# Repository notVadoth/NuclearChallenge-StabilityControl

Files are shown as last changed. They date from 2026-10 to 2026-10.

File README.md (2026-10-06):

# Nuclear Innovation Challenge: Reactor Stability Control (Dye Analogue)

A bench-scale analogue of reactor control for the 2026 Nuclear Innovation Challenge (Controls and Instrumentation track). Green food dye stands in for boron: adding dye "lowers the control rods", diluting with clear water "raises" them. A colour sensor reads the dye concentration, and pumps hold it at a target. The long-term goal is a holistic system that predicts unstable conditions and recommends actions before they happen.

Built on the challenge's base code: [IdeasClinicUWaterloo/F26-NuclearIC](https://github.com/IdeasClinicUWaterloo/F26-NuclearIC)

Canva view link: https://canva.link/ud9t2yi2hbv6vku

## Contents

| Folder | What it is |
| --- | --- |
| `Pump Control App/Pump Control.html` | Desktop control app. Open in Chrome or Edge, no install. Connects to the Arduino over USB (Web Serial). |
| `Pump Control App/pump_control_serial/` | Arduino sketch the app talks to: pumps, colour sensor, stored calibration, safety limits. |
| `Beaker Level Camera/Beaker Level Camera.html` | Standalone page that measures the tank level in mL from a phone used as a webcam. No Arduino needed. |
| `BeerLambertCalibrator/` | The repo's calibration sketch, extended to print live concentration and hold a saved calibration. Used from the Serial Monitor. |
| `dye_concentration_controller/` | The repo's controller sketch with a 10-second-per-pump test mode added, plus a local copy of the PID library (Brett Beauregard, MIT licence) so it compiles without installing it. |
| `Docs/Nuclear Innovation Challenge.pptx` | Group 9's presentation: challenge problem, background, the control rod simulator, experiment and observations, setbacks, safety and regulations, citations and AI disclosure. |
| `Docs/calibration-2026-10-03.svg` | Graph of the 3 Oct 2026 calibration: absorbance of the five standards against concentration, with the fitted line. |
| `Media/` | Photos of the rig, the bench setup, the control app in use and the team. |
| `Schematic/` | KiCad project of the rig's wiring (`dye-rig.kicad_sch`) and an SVG export of it (`dye-rig.svg`). |

## Hardware

Arduino UNO R4 Minima, SEN0101 (TCS3200) colour sensor, three 3 V pumps (dye, clear, waste) on two DRV8833 drivers powered by a 9 V battery, 500 mL control tank run at 350 mL (limit 450 mL). Pins follow `WIRING.md` in the base repo:

- Pumps: dye D3/D5, clear D6/D9, waste D10/D11 (PWM pin / held LOW)
- Sensor: OUT D2, S0 D4, S1 D7, S2 D8, S3 D12, OE to GND
- Sensor read through the red filter at 100 % scaling (green dye absorbs red); ambient room lighting

### Schematic

Drawn in KiCad; open `Schematic/dye-rig.kicad_pro` to edit it. The 9 V battery feeds both drivers' VCC, and its negative side is the common ground shared with the Arduino and the sensor. Driver 1 runs the dye pump (IN1/IN2 → OUT1/OUT2) and the clear pump (IN3/IN4 → OUT3/OUT4); driver 2 runs the waste pump (IN1/IN2 → OUT1/OUT2).

Wiring schematic: Arduino UNO R4 Minima, SEN0101 colour sensor, two DRV8833 driver modules, three pumps and the 9 V battery

## Running it

1. Upload `pump_control_serial.ino` from the Arduino IDE (board: Arduino UNO R4 Minima). Close the Serial Monitor afterwards.
2. Open `Pump Control.html` in Chrome or Edge, click **Connect to Arduino**, pick the board's COM port.
3. Enter the real tank level under **Actual level** and click **Set** before running pumps.

### App features

- Manual pump control: speed 56-80 (of 255) in steps of 2, timed runs with volume estimates, Stop all (Esc / Space).
- Live dye concentration, raw colour channels and a 10-minute trend graph.
- Calibration wizard (known concentrations, measured absorbance, fitted curve), saved to the Arduino's EEPROM.
- Automatic concentration control: doses dye or clear water in bursts at the selected speeds, waits for mixing, re-reads, repeats until within tolerance. Flushes after a set volume or before the tank could overflow.

## Beaker level camera

`Beaker Level Camera.html` reads the water level in the tank from a phone camera. Open it in Chrome or Edge; it runs on its own and does not connect to the Arduino.

1. Install a webcam app (Camo, Iriun or DroidCam) on the phone and laptop so the phone shows up as a camera, then pick it and click **Start camera**.
2. Fix the phone side-on to the beaker with the liquid line in view. It must not move afterwards.
3. Click **Mark A** and then a known level on the beaker (for example 350 mL), and do the same for **Mark B** at a second level (for example 450 mL).
4. Slide the measuring strip onto a clear part of the beaker, away from labels and tape. A striped card behind the beaker helps with clear water.

How it works: in a narrow vertical strip, each row's median colour is compared with the rows above and below it, and the strongest change is taken as the water surface. It can look for green dye, for any brightness edge (clear or faint water), or pick whichever is clearer automatically. Near-white LED glare is ignored. The two marks map image height to mL, assuming a straight-sided beaker. The reading is the median of the last 9 frames, and it is only marked as trusted when the line is strong, well above the strip's normal variation, steady to within 20 mL, and the picture is not frozen. Other code on the same page can use `window.levelTrusted()`, `window.levelWhy()` and the `beakerlevel` event (about 4 readings a second).

## Calibration

- Known concentration: `C = (drops x 0.05 mL) / 350 mL` (mL food dye / mL total)
- Measured absorbance: `A = -log10(f / f0)`, with `f0` the clear-water frequency
- Calibration curve: straight line `A = slope x C + intercept` (A on y, C on x), read the other way round for unknowns: `C = beta0 + beta1 x A`

Current default (3 Oct 2026, 4th standard estimated because its reading was faulty): `f0 = 6166.46 Hz`, `A = 390.29 C + 0.3656`, R² = 0.956, valid for 1-5 drops in 350 mL.

Calibration curve, 3 Oct 2026: absorbance against concentration for 1-5 drops in 350 mL, with the fitted line A = 390.29 C + 0.3656

| Drops | C (mL/mL) | f (Hz) | A |
| --- | --- | --- | --- |
| 1 | 0.000143 | 2386.79 | 0.4122 |
| 2 | 0.000286 | 2102.23 | 0.4674 |
| 3 | 0.000429 | 1676.50 | 0.5656 |
| 4 | 0.000571 | 1590.16 (estimated) | 0.5886 |
| 5 | 0.000714 | 1444.28 | 0.6304 |

## Measured pump flow (speed 60)

| Pump | Flow |
| --- | --- |
| Dye | 8.9 mL/s |
| Clear | 7.95 mL/s |
| Waste (flush) | 9.4 mL/s |

Runs vary by about ±10 mL, so volumes in the app are estimates.

## Safety built in

- Arduino: pumps start off; speed limited to 0 or 55-80; each run capped so one burst cannot overflow the tank; all pumps stop within 3 s if the app goes quiet.
- App: estimated tank level guards (stops inflow near 450 mL, waste at 100 mL); automatic control stops on sensor fault, Arduino safety stop, disconnect or Stop all.
- The pump app does not read a level sensor yet (the beaker level camera runs separately): always watch the tank.

## Photos from the build

| | |
| --- | --- |
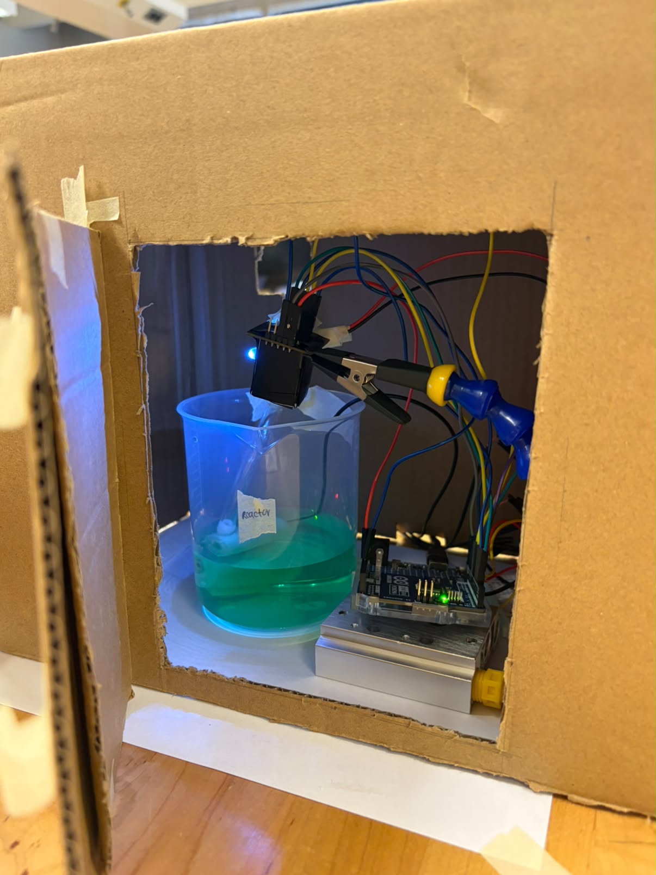
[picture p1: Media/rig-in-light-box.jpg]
The control tank ("Reactor") inside the cardboard light box, with the colour sensor clamped above it and the Arduino beside it
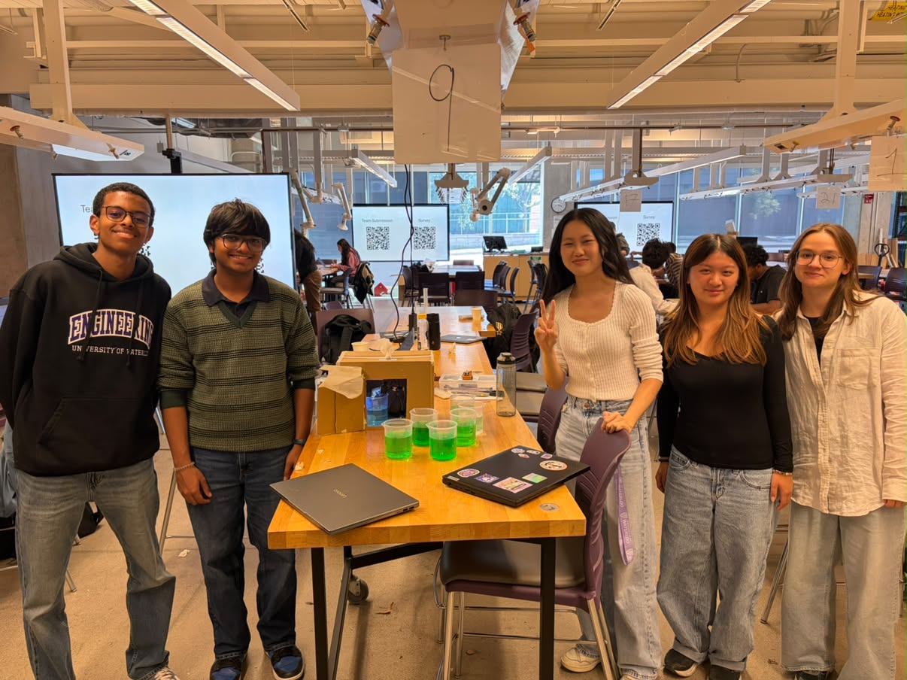
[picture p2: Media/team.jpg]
Group 9 with the rig and the dye standards at the Nuclear Innovation Challenge
|  |  |
| The control tank ("Reactor") in the closed light box, with the colour sensor clamped over it and the Arduino beside it. | Group 9 with the rig and the dye standards. |
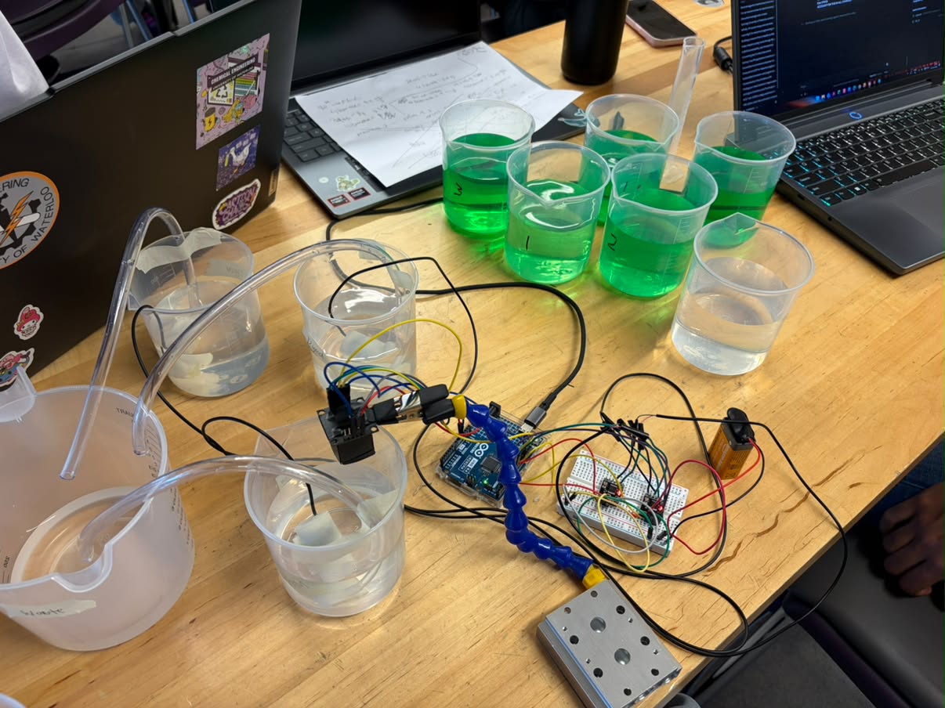
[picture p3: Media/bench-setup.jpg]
Bench setup: dye, clear and waste beakers with pump tubing, the colour sensor, Arduino, motor drivers on a breadboard and the 9 V battery, with the numbered calibration standards behind
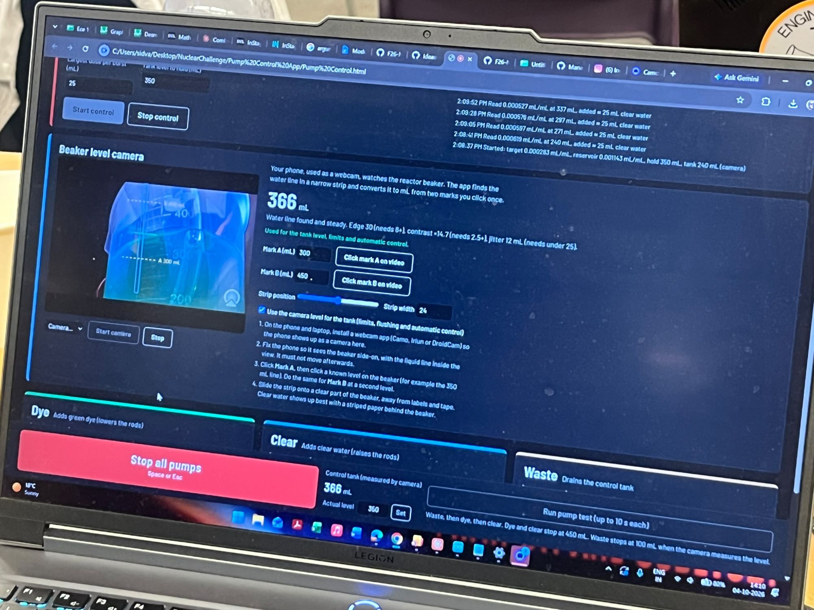
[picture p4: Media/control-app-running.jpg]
The control app during a test: automatic control log, the beaker level camera reading 366 mL, and the pump panels
|  |  |
| Bench setup before the box: dye, clear and waste beakers with pump tubing, the sensor, Arduino, DRV8833 drivers and 9 V battery, with the numbered calibration standards behind. | The control app during a test, with the beaker level camera reading the tank. This is the development version with the camera built into the app, which is not in this repository yet. |

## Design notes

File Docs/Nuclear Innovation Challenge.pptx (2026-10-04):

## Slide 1

Nuclear Innovation Challenge

Controls &
Instrumentation:
Control Rod Simulator (Dye Control Regulator)

Group 9: Siddharth, Zhiyu, Cecilia, Issa, Kira

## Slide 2

Challenge Problem :
For controller to regulate the same outputs within the limits of the existing physical constraints

Dye Concentration Regulator

Studying the flow, sensor accuracy, and system response

Physical System
(Reactor stability control)

State estimation and safety supervision

Comparing controllers over multiple tests, watching for “unsafe” conditions

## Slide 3

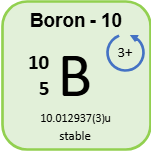
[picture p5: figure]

Relevance and Background

Relevance

  - SMRs use boron in their control rods
    - Controlling rate of reaction
  - Helped in past nuclear disasters
  - Too much boron, reactor shuts off
  - Too little boron, no coolant

Impact

  - Emergency shutdown (scram)

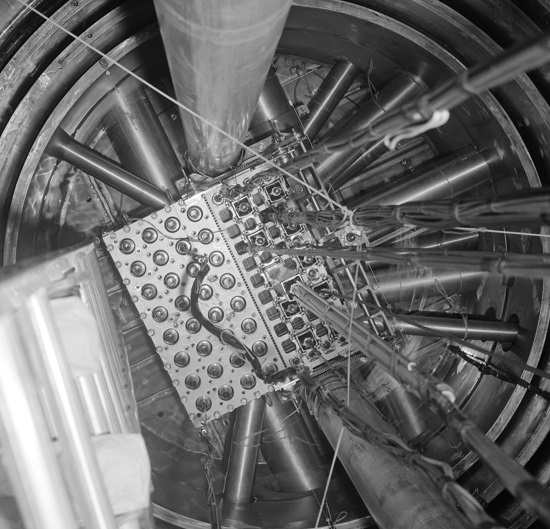
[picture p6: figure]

(Zoomie & Zoomie, 2024)

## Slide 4

Control Rod Simulator

Reactor

  - Starts as a clear solution
  - Dyed solution slowly feeded in until ideal concentration
  - Scram if no dye for too long

Waste Beaker

01

Clear
Solution

  - No dye here is added.
  - Feeds to reactor to dilute concentration when it’s too high

02

Dyed
solution

  - Green Dye simulates boron in control rods
  - Managing rate of reaction
  - Highly concentrated

03

Used to pump solution from the reactor so that the reactor doesn’t exceed 450mL.

04

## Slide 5

Pump Calibrations (Flow Rates) - false

Waste: 9.4mL/s
Clear: 7.95mL/s
Dye: 8.9mL/s

Concentration Calibrations

  - Got frequency from sensors
  - Calculate absorbance from frequency, verify concentration

Experiment and Observations

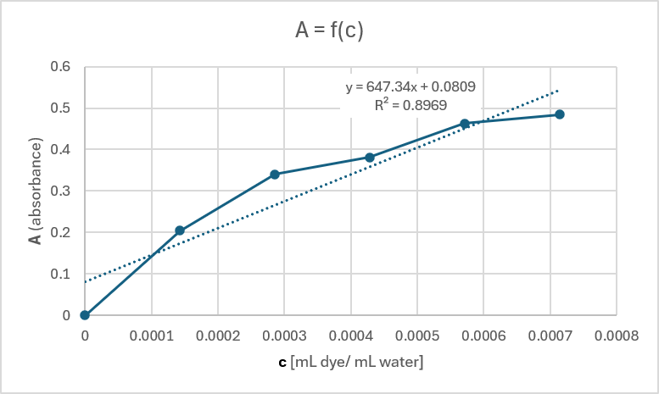
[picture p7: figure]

  - Find absorbtion using Beer-Lambert’s law and measured frequency from light sensor
  - Find concentration using:
c = (number of drops * 0.05ml) / 350ml
  - Measured flow rates for calibration
  - Created an app connected to the arduino, having separate buttons to control each flow

  - Minimized external light
  - Use camera sensors to measure water levels, to control the volume
  - Testing the controller

Graph showing A, absorbance, depending on c, concentration of mL of dye per mL of water)

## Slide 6

Setbacks

Concentration Calibration

  - Wrong calibration and anomalous values because of the use of two identical solutions
  - False usage of units
  - Unnessary flow calibrations

External Light

  - On second day, outside light became darker
  - Moved to a brighter area
  - Used cardboard box with incision for flashlight to minimize other light

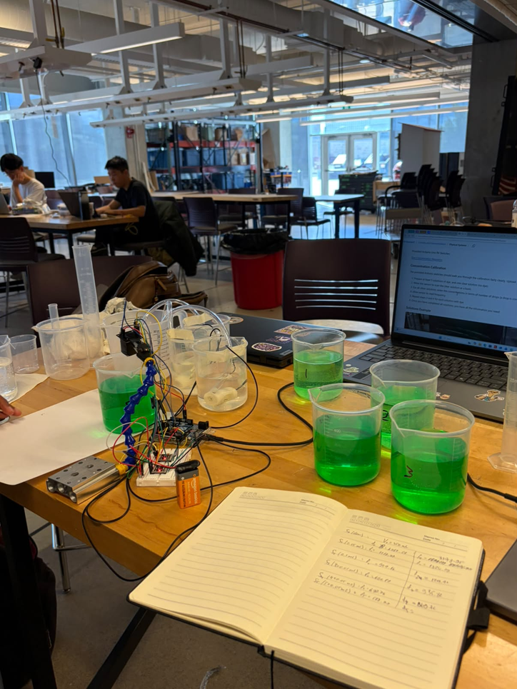
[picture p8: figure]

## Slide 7

Safety and Regulations

Managing concentration:

  - Ability to slow or halt fission
  - Disaster recognition

Stakeholder impact:

  - Minimizing nuclear disasters
  - Control rod lowering is automated - solution would not require further worker attention

Regulation alignment:

  - Nuclear safety control act 2.1.10: neutron detector requirement
  - Nuclear safety control act 2.2.5: neutron measurement system
(Government of Canada, Public Works and Government Services Canada, Public Services and Procurement Canada, Integrated Services Branch, Canada Gazette, 2025)

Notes: https://gazette.gc.ca/rp-pr/p2/2025/2025-10-08/html/sor-dors196-eng.html

A.2.1.10 Neutron detectors
Especially designed or prepared neutron detectors for determining neutron flux levels within the core of a nuclear reactor within the meaning of paragraph A.2.1.1.

A.2.2.5 Neutron measurement systems for process control
Neutron measurement systems especially designed or prepared for integration and use with automated process control systems in reprocessing plants referred to in paragraph A.2.2.

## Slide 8

Citations

Government of Canada, Public Works and Government Services Canada, Public Services
and Procurement Canada, Integrated Services Branch, Canada Gazette. (2025, October 9).
Canada Gazette, Part 2, Volume 159, Number 21: Regulations amending certain regulations made under the Nuclear Safety and Control Act (Imports, Exports and Safeguards). https://gazette.gc.ca/rp-pr/p2/2025/2025-10-08/html/sor-dors196-eng.html
Borates in nuclear energy: Preventive and emergency nuclear safety. (n.d.). https://www.borax.com/applications/nuclear-energy
Zoomie, & Zoomie. (2024, May 5). Control rods in nuclear reactors – it’s all about neutrons. Nevada Technical Associates, Inc. |. https://www.ntanet.net/control-rods-in-nuclear-reactors-its-all-about-neutrons/

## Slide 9

AI Disclosure

AID Statement: Artificial Intelligence Tool: Claude (app, pro version); Conceptualization: Used to simplify some technical concepts mentioned in GitHub and explain in the simple way the functionality of the control rods in SMR; Execution: Modified and debugged the code used to run the Arduino to simulate the physical system of the dye concentration regulator; Visualization: Generated an app/dashboard Pump Control that gives commands to Arduino and is used to regulate the running pump tests, while adapting to the base dye concentration control. Generated the graph of concentration levels.

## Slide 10

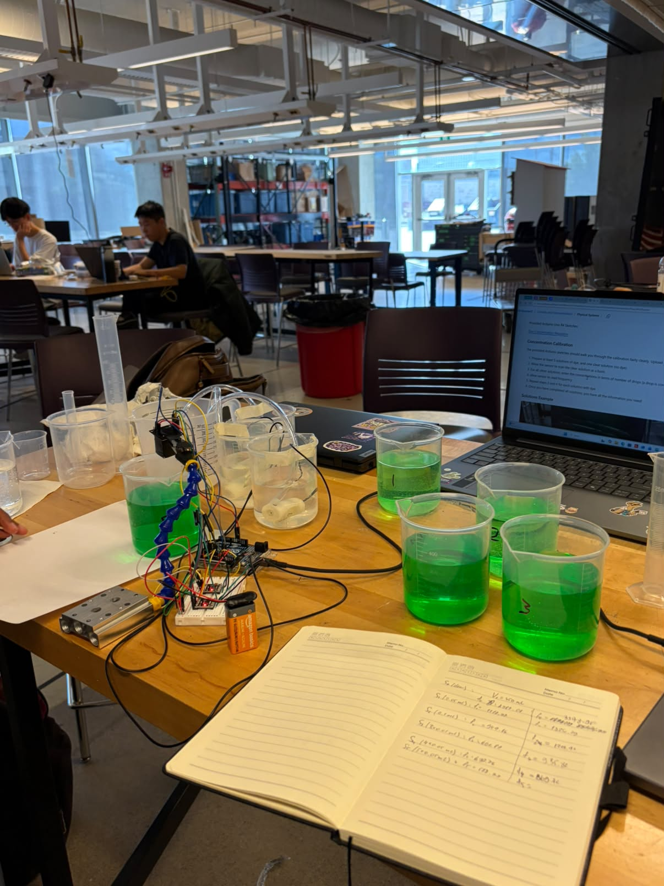
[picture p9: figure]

Thank You

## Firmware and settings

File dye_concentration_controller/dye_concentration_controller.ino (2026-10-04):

// Physical dye-concentration controller
//
// Hardware:
//   - Arduino UNO R4 Minima
//   - DFRobot SEN0101 / TCS3200 frequency-output colour sensor
//   - 3 x 3 V submersible pumps
//   - 2 x DRV8833 dual H-bridge motor drivers
//
// The dye and clear-water pumps are the two channels of Driver 1. The waste
// pump uses OUT1/OUT2 of Driver 2. Each pump runs in one direction: PWM is
// applied to IN1 while IN2 is held LOW.
// The physical control tank is a 500 mL cup with a strict 450 mL liquid limit.
// Commission at about 350 mL and calibrate the sensor at that same volume. This
// sketch has no level sensor, so its flow-based waste command is not an
// independent overflow safeguard.
//
// Two control modes are available:
//   1. INTENSITY_BAND_MODE targets a raw sensor frequency with a +/- tolerance.
//      It does not require conversion to physical concentration units.
//   2. CALIBRATED_CONCENTRATION_PID_MODE converts frequency to concentration
//      using measured standards, then runs PID in concentration units.

#include "PID_v1.h" // originally <PID_v1.h>; quotes use the PID copy in this sketch folder

// ---------------- SEN0101 / TCS3200 pins ----------------
const uint8_t SENSOR_OUT_PIN = 2;
const uint8_t SENSOR_S0_PIN  = 4;
const uint8_t SENSOR_S1_PIN  = 7;
const uint8_t SENSOR_S2_PIN  = 8;
const uint8_t SENSOR_S3_PIN  = 12;

// OE is tied directly to GND in the wiring guide, so no Arduino pin is needed.

// ---------------- DRV8833 pump pins ----------------
const uint8_t DYE_PUMP_PWM_PIN     = 3; // Driver 1 IN1
const uint8_t DYE_PUMP_LOW_PIN     = 5; // Driver 1 IN2
const uint8_t WATER_PUMP_PWM_PIN   = 6; // Driver 1 IN3
const uint8_t WATER_PUMP_LOW_PIN   = 9; // Driver 1 IN4
const uint8_t WASTE_PUMP_PWM_PIN   = 10; // Driver 2 IN1
const uint8_t WASTE_PUMP_LOW_PIN   = 11; // Driver 2 IN2

// If exposed, each DRV8833 SLP/SLEEP/nSLEEP pin is tied to Arduino 5V.

// ---------------- TCS3200 colour filters ----------------
enum ColourChannel : uint8_t {
  RED_FILTER,
  BLUE_FILTER,
  CLEAR_FILTER,
  GREEN_FILTER
};

// Red dye often produces its largest useful change in the green channel, but
// this must be confirmed with test_rgb.ino. Change this constant if another
// channel gives a larger, smoother and monotonic calibration curve.
const ColourChannel CONCENTRATION_CHANNEL = GREEN_FILTER;

const unsigned long SENSOR_PULSE_TIMEOUT_US = 50000;
const uint8_t SENSOR_PERIOD_SAMPLES = 12;

// ---------------- Control-mode selection ----------------
enum DyeControlMode : uint8_t {
  INTENSITY_BAND_MODE,
  CALIBRATED_CONCENTRATION_PID_MODE
};

// Raw intensity mode is the simpler default. Use test_rgb.ino to measure the
// desired mixture, enter its frequency below, and confirm whether adding dye
// makes that frequency rise or fall.
const DyeControlMode CONTROL_MODE = INTENSITY_BAND_MODE;
const float TARGET_INTENSITY_HZ = 0.0; // replace with the desired measured value
const float INTENSITY_TOLERANCE_HZ = 100.0;
const bool DYE_MAKES_INTENSITY_DECREASE = true;
const int INTENSITY_CORRECTION_PWM = 140;

// ---------------- Pump test mode (added for hardware testing) ----------------
// When PUMP_TEST_MODE is true, setup() runs each pump on its own for
// PUMP_TEST_DURATION_MS, one after another, then turns every pump OFF.
// The normal control loop does not run while this is true.
// Send 't' in the Serial Monitor (9600 baud) to repeat the test.
// Set PUMP_TEST_MODE to false to return to normal control.
//
// Order is waste -> dye -> clear so the tank level dips first, then refills.
// Starting at 350 mL this keeps the tank between the pump-submerged level and
// the 450 mL limit, as long as each pump moves no more than about 70 mL in 10 s.
// Watch the tank during the test anyway: there is no level sensor.
const bool PUMP_TEST_MODE = true;
const unsigned long PUMP_TEST_DURATION_MS = 10000; // 10 seconds per pump
const unsigned long PUMP_TEST_GAP_MS = 2000;       // pause between pumps
const int PUMP_TEST_PWM = INTENSITY_CORRECTION_PWM; // same drive level the controller uses

// ---------------- Intensity -> concentration calibration ----------------
// Use test_rgb.ino and the procedure in Physical Systems/README.md.
//
// Set CAL_POINT_COUNT to the number of standards and enter at least two
// measured points. More points are strongly recommended.
// Standards are measured dilutions of the same prepared dyed-water reservoir
// solution used by the pump. Concentration can be an absolute unit (when the
// reservoir concentration is known) or reservoir-solution volume percent. The
// target below MUST use the same unit and remain inside the calibrated range.
//
// Keep points ordered by increasing concentration. Intensity may increase or
// decrease, but it must move monotonically across the table.
const bool CALIBRATION_READY = false;
const uint8_t CAL_POINT_COUNT = 2;
const float CAL_INTENSITY_HZ[CAL_POINT_COUNT] = {
  0.0, 0.0 // replace with measured SEN0101 frequencies
};
const float CAL_CONCENTRATION[CAL_POINT_COUNT] = {
  0.0, 0.0 // replace with the corresponding known concentrations
};

// ---------------- Concentration PID ----------------
double measuredConcentration = 0.0;
double targetConcentration   = 5.0; // replace; same unit as CAL_CONCENTRATION
double pidOutput              = 0.0; // -255..255: +dye, -clear water

// Starting points only. Tune on the assembled, calibrated apparatus.
double Kp = 4.0;
double Ki = 0.5;
double Kd = 0.2;

PID concentrationPID(
    &measuredConcentration,
    &pidOutput,
    &targetConcentration,
    Kp,
    Ki,
    Kd,
    DIRECT);

// ---------------- PWM -> flow calibration ----------------
// Measure each pump separately. The initial values are placeholders.
struct FlowCalibration {
  double slope;
  double intercept;
};

FlowCalibration dyeFlow  = {0.40, 0.0};
FlowCalibration waterFlow = {0.45, 0.0};
FlowCalibration wasteFlow = {0.50, 0.0};

int dyePwm = 0;
int waterPwm = 0;
int wastePwm = 0;

double pwmToFlow(int pwm, FlowCalibration calibration) {
  if (pwm <= 0) return 0.0;
  return max(0.0, calibration.slope * pwm + calibration.intercept);
}
int flowToPwm(double flow, FlowCalibration calibration) {
  if (flow <= 0.0 || calibration.slope <= 0.0) return 0;
  return constrain(
      (int)((flow - calibration.intercept) / calibration.slope + 0.5),
      0,
      255);
}

void selectColourChannel(ColourChannel channel) {
  switch (channel) {
    case RED_FILTER:   // S2 LOW,  S3 LOW
      digitalWrite(SENSOR_S2_PIN, LOW);
      digitalWrite(SENSOR_S3_PIN, LOW);
      break;
    case BLUE_FILTER:  // S2 LOW,  S3 HIGH
      digitalWrite(SENSOR_S2_PIN, LOW);
      digitalWrite(SENSOR_S3_PIN, HIGH);
      break;
    case CLEAR_FILTER: // S2 HIGH, S3 LOW
      digitalWrite(SENSOR_S2_PIN, HIGH);
      digitalWrite(SENSOR_S3_PIN, LOW);
      break;
    case GREEN_FILTER: // S2 HIGH, S3 HIGH
      digitalWrite(SENSOR_S2_PIN, HIGH);
      digitalWrite(SENSOR_S3_PIN, HIGH);
      break;
  }

  delay(3); // allow the photodiode filter selection to settle
}

float readFrequencyHz(ColourChannel channel) {
  selectColourChannel(channel);

  unsigned long totalPeriodUs = 0;
  uint8_t validPeriods = 0;

  for (uint8_t i = 0; i < SENSOR_PERIOD_SAMPLES; ++i) {
    const unsigned long lowUs =
        pulseIn(SENSOR_OUT_PIN, LOW, SENSOR_PULSE_TIMEOUT_US);
    const unsigned long highUs =
        pulseIn(SENSOR_OUT_PIN, HIGH, SENSOR_PULSE_TIMEOUT_US);

    if (lowUs > 0 && highUs > 0) {
      totalPeriodUs += lowUs + highUs;
      ++validPeriods;
    }
  }

  if (validPeriods == 0 || totalPeriodUs == 0) return NAN;
  return 1000000.0f * validPeriods / totalPeriodUs;
}

bool calibrationTableIsValid() {
  if (!CALIBRATION_READY || CAL_POINT_COUNT < 2) return false;

  const bool intensityIncreasing =
      CAL_INTENSITY_HZ[1] > CAL_INTENSITY_HZ[0];

  for (uint8_t i = 0; i < CAL_POINT_COUNT; ++i) {
    if (CAL_INTENSITY_HZ[i] <= 0.0) return false;
    if (i == 0) continue;
    if (CAL_CONCENTRATION[i] <= CAL_CONCENTRATION[i - 1]) return false;
    if (CAL_INTENSITY_HZ[i] == CAL_INTENSITY_HZ[i - 1]) return false;
    if ((CAL_INTENSITY_HZ[i] > CAL_INTENSITY_HZ[i - 1]) !=
        intensityIncreasing) {
      return false;
    }
  }

  return true;
}

double intensityToConcentration(float intensityHz) {
  // Linear interpolation between measured standards. This supports either an
  // increasing or decreasing sensor response.
  for (uint8_t i = 0; i < CAL_POINT_COUNT - 1; ++i) {
    const float x0 = CAL_INTENSITY_HZ[i];
    const float x1 = CAL_INTENSITY_HZ[i + 1];
    const float low = min(x0, x1);
    const float high = max(x0, x1);

    if (intensityHz >= low && intensityHz <= high) {
      const double fraction = (intensityHz - x0) / (x1 - x0);
      return CAL_CONCENTRATION[i] +
             fraction * (CAL_CONCENTRATION[i + 1] - CAL_CONCENTRATION[i]);
    }
  }

  // Clamp out-of-range readings to the nearest calibrated endpoint. The
  // controller should not extrapolate beyond concentrations it has seen.
  const float distanceToFirst = abs(intensityHz - CAL_INTENSITY_HZ[0]);
  const float distanceToLast =
      abs(intensityHz - CAL_INTENSITY_HZ[CAL_POINT_COUNT - 1]);
  return (distanceToFirst <= distanceToLast)
      ? CAL_CONCENTRATION[0]
      : CAL_CONCENTRATION[CAL_POINT_COUNT - 1];
}

void setPump(uint8_t pwmPin, uint8_t lowPin, int pwm) {
  pwm = constrain(pwm, 0, 255);
  digitalWrite(lowPin, LOW);
  analogWrite(pwmPin, pwm);
}

void stopAllPumps() {
  dyePwm = 0;
  waterPwm = 0;
  wastePwm = 0;
  setPump(DYE_PUMP_PWM_PIN, DYE_PUMP_LOW_PIN, 0);
  setPump(WATER_PUMP_PWM_PIN, WATER_PUMP_LOW_PIN, 0);
  setPump(WASTE_PUMP_PWM_PIN, WASTE_PUMP_LOW_PIN, 0);
}

// Runs one pump for PUMP_TEST_DURATION_MS with every other pump OFF.
void testOnePump(const __FlashStringHelper *name, uint8_t pwmPin, uint8_t lowPin) {
  stopAllPumps();
  Serial.print(F("PUMP TEST: "));
  Serial.print(name);
  Serial.print(F(" pump ON for "));
  Serial.print(PUMP_TEST_DURATION_MS / 1000);
  Serial.print(F(" s at PWM "));
  Serial.println(PUMP_TEST_PWM);

  setPump(pwmPin, lowPin, PUMP_TEST_PWM);
  const unsigned long startMs = millis();
  while (millis() - startMs < PUMP_TEST_DURATION_MS) {
    // Countdown once per second so you can see the test is running.
    const unsigned long elapsed = millis() - startMs;
    if (elapsed % 1000 < 20) {
      Serial.print(F("  "));
      Serial.print((PUMP_TEST_DURATION_MS - elapsed + 999) / 1000);
      Serial.println(F(" s left"));
      delay(20);
    }
  }
  stopAllPumps();

  Serial.print(F("PUMP TEST: "));
  Serial.print(name);
  Serial.println(F(" pump OFF"));
  delay(PUMP_TEST_GAP_MS);
}

void runPumpTest() {
  Serial.println(F("=== PUMP TEST START: waste, dye, clear (10 s each) ==="));
  testOnePump(F("WASTE"), WASTE_PUMP_PWM_PIN, WASTE_PUMP_LOW_PIN);
  testOnePump(F("DYE"),   DYE_PUMP_PWM_PIN,   DYE_PUMP_LOW_PIN);
  testOnePump(F("CLEAR"), WATER_PUMP_PWM_PIN, WATER_PUMP_LOW_PIN);
  stopAllPumps();
  Serial.println(F("=== PUMP TEST DONE: all pumps OFF. Send 't' to run again. ==="));
}

void setup() {
  Serial.begin(9600);
  while (!Serial && millis() < 3000) {}

  pinMode(SENSOR_OUT_PIN, INPUT);
  pinMode(SENSOR_S0_PIN, OUTPUT);
  pinMode(SENSOR_S1_PIN, OUTPUT);
  pinMode(SENSOR_S2_PIN, OUTPUT);
  pinMode(SENSOR_S3_PIN, OUTPUT);

  // TCS3200 output-frequency scaling: S0 LOW + S1 HIGH = 2%.
  // This keeps pulse periods long enough for reliable pulseIn() measurement.
  digitalWrite(SENSOR_S0_PIN, LOW);
  digitalWrite(SENSOR_S1_PIN, HIGH);

  // Preload safe states before enabling the pump pins as outputs.
  digitalWrite(DYE_PUMP_PWM_PIN, LOW);
  digitalWrite(DYE_PUMP_LOW_PIN, LOW);
  digitalWrite(WATER_PUMP_PWM_PIN, LOW);
  digitalWrite(WATER_PUMP_LOW_PIN, LOW);
  digitalWrite(WASTE_PUMP_PWM_PIN, LOW);
  digitalWrite(WASTE_PUMP_LOW_PIN, LOW);

  pinMode(DYE_PUMP_PWM_PIN, OUTPUT);
  pinMode(DYE_PUMP_LOW_PIN, OUTPUT);
  pinMode(WATER_PUMP_PWM_PIN, OUTPUT);
  pinMode(WATER_PUMP_LOW_PIN, OUTPUT);
  pinMode(WASTE_PUMP_PWM_PIN, OUTPUT);
  pinMode(WASTE_PUMP_LOW_PIN, OUTPUT);
  stopAllPumps();

  concentrationPID.SetOutputLimits(-255, 255);
  concentrationPID.SetSampleTime(500);

  if (CONTROL_MODE == INTENSITY_BAND_MODE) {
    concentrationPID.SetMode(MANUAL);
    if (TARGET_INTENSITY_HZ > 0.0 && INTENSITY_TOLERANCE_HZ >= 0.0) {
      Serial.println(F("Raw intensity-band control enabled."));
    } else {
      Serial.println(F("SET TARGET_INTENSITY_HZ: all pumps remain OFF until it is positive."));
    }
  } else if (calibrationTableIsValid()) {
    concentrationPID.SetMode(AUTOMATIC);
    Serial.println(F("Calibrated concentration PID enabled."));
  } else {
    concentrationPID.SetMode(MANUAL);
    Serial.println(F("CALIBRATION REQUIRED for concentration PID: pumps OFF."));
    Serial.println(F("Run rgb/test_rgb/test_rgb.ino and enter real calibration points."));
  }

  if (PUMP_TEST_MODE) {
    runPumpTest();
  }
}

void loop() {
  // Pump test mode: keep pumps OFF and wait for 't' to repeat the test.
  // The normal control code below is skipped while PUMP_TEST_MODE is true.
  if (PUMP_TEST_MODE) {
    stopAllPumps();
    if (Serial.available() > 0) {
      const char c = Serial.read();
      if (c == 't' || c == 'T') runPumpTest();
    }
    delay(50);
    return;
  }

  const float intensityHz = readFrequencyHz(CONCENTRATION_CHANNEL);

  if (isnan(intensityHz) || intensityHz <= 0.0) {
    stopAllPumps();
    Serial.println(F("SENSOR FAULT: no SEN0101 frequency; pumps OFF"));
    delay(500);
    return;
  }

  if (CONTROL_MODE == INTENSITY_BAND_MODE) {
    if (TARGET_INTENSITY_HZ <= 0.0 || INTENSITY_TOLERANCE_HZ < 0.0) {
      stopAllPumps();
      Serial.print(F("set_target intensity_hz="));
      Serial.println(intensityHz, 2);
      delay(500);
      return;
    }

    const float intensityError = intensityHz - TARGET_INTENSITY_HZ;
    if (abs(intensityError) <= INTENSITY_TOLERANCE_HZ) {
      dyePwm = 0;
      waterPwm = 0;
    } else {
      // Determine whether the mixture needs more dye without assuming which
      // direction the selected sensor channel moves.
      const bool needsMoreDye = DYE_MAKES_INTENSITY_DECREASE
          ? intensityHz > TARGET_INTENSITY_HZ
          : intensityHz < TARGET_INTENSITY_HZ;
      dyePwm = needsMoreDye ? INTENSITY_CORRECTION_PWM : 0;
      waterPwm = needsMoreDye ? 0 : INTENSITY_CORRECTION_PWM;
    }
  } else {
    if (!calibrationTableIsValid()) {
      stopAllPumps();
      Serial.print(F("calibration_required intensity_hz="));
      Serial.println(intensityHz, 2);
      delay(500);
      return;
    }

    measuredConcentration = intensityToConcentration(intensityHz);
    concentrationPID.Compute();

    if (pidOutput >= 0.0) {
      dyePwm = constrain((int)(pidOutput + 0.5), 0, 255);
      waterPwm = 0;
    } else {
      dyePwm = 0;
      waterPwm = constrain((int)(-pidOutput + 0.5), 0, 255);
    }
  }

  const double totalInflow =
      pwmToFlow(dyePwm, dyeFlow) + pwmToFlow(waterPwm, waterFlow);
  wastePwm = flowToPwm(totalInflow, wasteFlow);

  setPump(DYE_PUMP_PWM_PIN, DYE_PUMP_LOW_PIN, dyePwm);
  setPump(WATER_PUMP_PWM_PIN, WATER_PUMP_LOW_PIN, waterPwm);
  setPump(WASTE_PUMP_PWM_PIN, WASTE_PUMP_LOW_PIN, wastePwm);

  Serial.print(F("intensity_hz="));
  Serial.print(intensityHz, 2);
  if (CONTROL_MODE == INTENSITY_BAND_MODE) {
    Serial.print(F(" target_intensity_hz="));
    Serial.print(TARGET_INTENSITY_HZ, 2);
    Serial.print(F(" tolerance_hz="));
    Serial.print(INTENSITY_TOLERANCE_HZ, 2);
  } else {
    Serial.print(F(" concentration="));
    Serial.print(measuredConcentration, 3);
    Serial.print(F(" target_concentration="));
    Serial.print(targetConcentration, 3);
  }
  Serial.print(F(" dye_pwm="));
  Serial.print(dyePwm);
  Serial.print(F(" water_pwm="));
  Serial.print(waterPwm);
  Serial.print(F(" waste_pwm="));
  Serial.println(wastePwm);

  delay(100);
}

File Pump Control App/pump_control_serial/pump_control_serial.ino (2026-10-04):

// Pump control + colour sensor over USB serial  (v3)
//
// Lets the "Pump Control" app on the computer drive the three pumps of the
// dye-concentration rig, read the SEN0101 colour sensor live, and store a
// Beer-Lambert calibration. Pins match WIRING.md and the repo sketches.
//
// The pumps are still controlled by hand from the app. Closed-loop control
// from the sensor (pumps reacting to concentration) comes at a later stage.
//
// Hardware (Arduino UNO R4 Minima):
//   Pumps - 2 x DRV8833 motor drivers on the 9 V battery rail
//     Dye pump   : Driver 1 IN1/IN2 -> D3 (PWM) / D5 (held LOW)
//     Clear pump : Driver 1 IN3/IN4 -> D6 (PWM) / D9 (held LOW)
//     Waste pump : Driver 2 IN1/IN2 -> D10 (PWM) / D11 (held LOW)
//   Colour sensor - SEN0101 / TCS3200, powered from Arduino 5V, OE tied to GND
//     OUT -> D2, S0 -> D4, S1 -> D7, S2 -> D8, S3 -> D12
//
// Sensor method (from the repo sketches):
//   - The TCS3200 outputs a square wave whose frequency rises with light
//     intensity. Frequency is averaged over several full periods
//     (pulseIn LOW + HIGH), as in test_rgb.ino / dye_concentration_controller.ino.
//   - Beer-Lambert (BeerLambertCalibrator.ino):
//       absorbance  A = -log10(f / f_clear)
//       concentration C = beta0 + beta1 * A     (mL food dye / mL water)
//     f_clear is the frequency through 350 mL of clear water. Standards are
//     made by adding drops (0.05 mL each) of the same dyed reservoir solution
//     the pump uses to 350 mL of water.
//   - Use the colour filter the dye absorbs most. Green dye absorbs red light,
//     so the RED filter is the default (BeerLambertCalibrator maps g -> red).
//   - Keep the sensor, flashlight, 350 mL volume and box closed and unchanged
//     between calibration and use. Any change to lighting invalidates it.
//
// Serial: 115200 baud, one command per line (newline terminated):
//   Pumps
//     SET <D|C|W> <0 or 55-80>     run a pump at that speed until stopped or capped
//     RUN <D|C|W> <55-80> <secs>   run a pump for a set time (up to its cap)
//     STOP                         stop every pump at once
//   Sensor
//     CHAN <R|G|B|C>               colour filter used for concentration
//     SCALE <2|20|100>             TCS3200 output-frequency scaling, in %
//     SAMPLE <n>                   average n readings of the chosen filter
//   Calibration (saved in the Arduino's EEPROM, survives power-off)
//     CAL SET <f_clear> <beta0> <beta1> <A_min> <A_max> <R|G|B|C> <scale>
//     CAL GET                      report the stored calibration
//     CAL CLEAR                    erase it (falls back to the spreadsheet calibration)
//   Link
//     PING                         keep-alive from the app
//     STATUS                       report pump state now
//
// The Arduino sends:
//   READY pump_control_serial v3
//   STATE D=140,0 C=0,0 W=140,8500     (pwm, ms left on a timed run; 0 = untimed)
//   SENS ch=R sc=20 r=.. g=.. b=.. c=.. f=.. a=.. conc=..   (Hz; nan if no signal)
//   SAMPLE ch=R sc=20 n=30 ok=30 mean=.. sd=.. min=.. max=..
//   CAL f0=.. b0=.. b1=.. amin=.. amax=.. ch=R sc=20   or   CAL none
//   OK ... / ERR ... / SAFETY ...
//
// Safety:
//   - All pumps start OFF.
//   - If no command or PING arrives for WATCHDOG_MS, every pump stops.
//   - Speed is 0 (off) or SPEED_MIN..SPEED_MAX (55..80 of 255). Anything else is
//     rejected. The 9 V supply overdrives the 3 V pumps at higher settings.
//   - Each pump has its own maximum single run, sized from its measured flow so
//     one run cannot overflow the tank (350 mL working, 450 mL limit).
//   - There is no level sensor: watch the tank and keep it under 450 mL.

#include <EEPROM.h>
#include <math.h>

// ---------------- Pins ----------------
const uint8_t DYE_PUMP_PWM_PIN   = 3;  // Driver 1 IN1
const uint8_t DYE_PUMP_LOW_PIN   = 5;  // Driver 1 IN2
const uint8_t CLEAR_PUMP_PWM_PIN = 6;  // Driver 1 IN3
const uint8_t CLEAR_PUMP_LOW_PIN = 9;  // Driver 1 IN4
const uint8_t WASTE_PUMP_PWM_PIN = 10; // Driver 2 IN1
const uint8_t WASTE_PUMP_LOW_PIN = 11; // Driver 2 IN2

const uint8_t SENSOR_OUT_PIN = 2;
const uint8_t SENSOR_S0_PIN  = 4;
const uint8_t SENSOR_S1_PIN  = 7;
const uint8_t SENSOR_S2_PIN  = 8;
const uint8_t SENSOR_S3_PIN  = 12;

// ---------------- Timing / safety ----------------
const unsigned long BAUD = 115200;
const unsigned long WATCHDOG_MS = 3000;       // stop pumps if the app goes quiet
// Allowed speeds (PWM out of 255). 0 = off.
const int SPEED_MIN = 55;
const int SPEED_MAX = 80;

// Measured flow at speed 60 (bench test, 3 Oct 2026), mL/s:
//   Dye 8.9   Clear 7.95   Waste (flush) 9.4
// Flow at other speeds is estimated in proportion (flow * speed / 60) until
// more speeds are measured.
const float FLOW60_DYE   = 8.9f;
const float FLOW60_CLEAR = 7.95f;
const float FLOW60_WASTE = 9.4f;

// The longest single run is sized from the flow so one run can never move more
// than this volume. From the 350 mL working level:
//   inflow (dye, clear): +95 mL  -> ~445 mL, under the 450 mL limit
//   waste             : -250 mL -> ~100 mL
//   e.g. speed 60: dye 10.7 s, clear 11.9 s, waste 26.6 s
//        speed 80: dye  8.0 s, clear  9.0 s, waste 20.0 s
const float MAX_INFLOW_PER_RUN_ML = 95.0f;
const float MAX_WASTE_PER_RUN_ML  = 250.0f;
const unsigned long STATE_REPORT_MS = 250;    // how often STATE lines are sent
const unsigned long SENSOR_REPORT_MS = 500;   // how often SENS lines are sent

// ---------------- Sensor settings ----------------
// pulseIn timeout per half-period. At 2 % scaling and low light a half-period
// can be tens of ms, so this is generous; a reading aborts on the first timeout.
const unsigned long SENSOR_PULSE_TIMEOUT_US = 60000;
const uint8_t LIVE_PERIODS   = 8;   // periods averaged per live reading
const uint8_t SAMPLE_PERIODS = 12;  // periods averaged per SAMPLE reading
const uint8_t MAX_SAMPLE_N   = 60;

char sensorChannel = 'R';   // R G B C  (red filter by default for green dye)
uint8_t sensorScale = 100;  // 2, 20 or 100 % (100 % matches BeerLambertCalibrator / ConcentrationRegulator)

// ---------------- Calibration (EEPROM) ----------------
const uint32_t CAL_MAGIC = 0x44594531; // "DYE1"
struct Calibration {
  uint32_t magic;
  float fClear;   // Hz through clear water
  float beta0;    // C = beta0 + beta1 * A
  float beta1;
  float aMin;     // absorbance range covered by the standards
  float aMax;
  char channel;   // filter used
  uint8_t scale;  // scaling used
};
Calibration cal;
bool calValid = false;
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

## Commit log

2026-10-04 Dye-concentration reactor analogue: control app, Arduino sketches, calibration
    Claude-Session: https://claude.ai/code/session_011pBcDPzLNPHKaqmRdXeLjh
2026-10-04 Add Beaker Level Camera: standalone phone-webcam tank level page
2026-10-04 Describe Beaker Level Camera; add presentation and 3 Oct calibration graph
2026-10-06 Add KiCad wiring schematic and a Schematic section in the README
    [dye-rig.kicad_sch]
